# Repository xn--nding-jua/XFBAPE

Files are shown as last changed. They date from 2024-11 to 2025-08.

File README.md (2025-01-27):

# X-f/bape - A DIY expansion-card for the Behringer X32

This repository contains the firmware for the X-f/bape DIY-ExpansionCard for the Behringer X32. This project
is based on the f/bape Audioplayer-project.

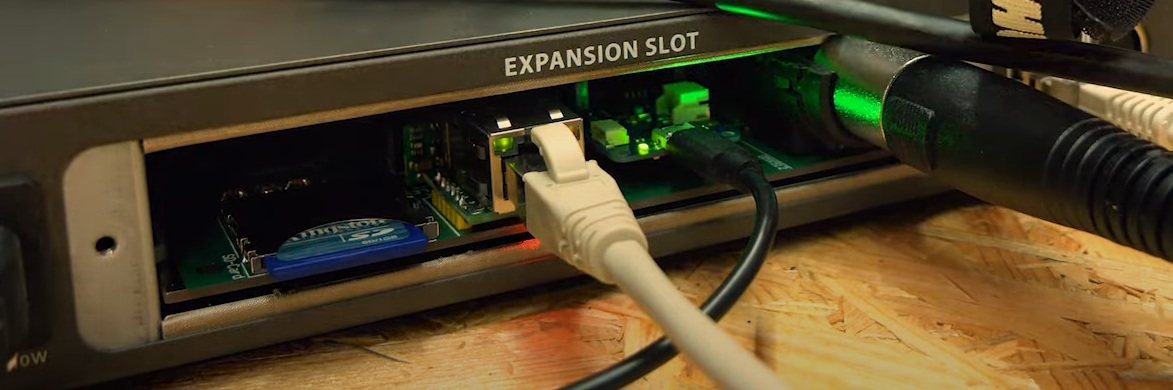
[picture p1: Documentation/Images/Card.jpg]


(https://www.youtube.com/watch?v=Q8K0aeqDBiI)

Three individual devices are part of this repository:

* Atmel/Microchip SAMD21 ATSAMD21G18A Cortex-M0+ 32-Bit Microcontroller
* Intel Cyclone 10LP 10CL016 FPGA
* uBlox NINA W102 (ESP32 D0WDQ6 Dual-Core)

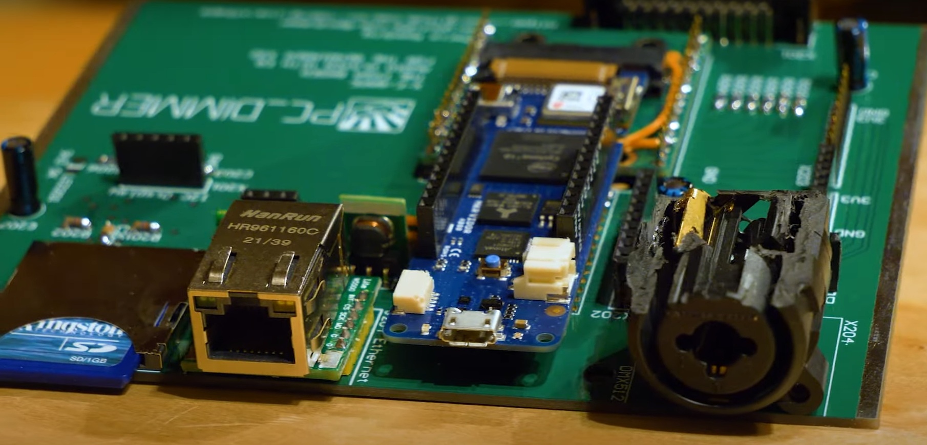
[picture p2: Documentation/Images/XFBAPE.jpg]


## Main-Features of the system
- [x] Card receives, mix and sends 32 audio-channels with 48kHz and 24bit
- [x] MP3-Playback via SD-Card
- [x] Card-playback can be controlled via original X32-Card-interface
- [x] Control via Webinterface (only WiFi and only Audio yet)
- [x] Control via multiple X-Touch-controls via ethernet (Audio and DMX512)
- [x] Control via original Behringer X32Edit (via ethernet)
- [x] Control via X32-surface using MackieMCU-emulation via Card-MIDI (Audio and DMX512)
- [x] Control via ASCII-based commands via USB, WiFi and Ethernet (Audio and DMX512)
- [x] DMX512-output (adjustable DMX-timings via VHDL)
- [x] Parametric-Equalizers (3 to 5, depending on the free space in FPGA)
- [x] Dynamic Audio-Compression (Stereo)

Optional / prepared features:
- [x] control card via MQTT when using NINA W102 in Client-Mode WiFi
- [x] multi-channel analog Audio-Output via PDM / sigma-delta-modulation
- [x] Noise-Gates
- [x] Bluetooth-A2DP-Sink (larger ESP32 is nescessary)
- [x] 24dB/oct Linkwitz-Riley Crossover for tweeter and subwoofer (larger FPGA is nescessary)

## Current status of the project
This project is ready for smaller events. Audio-processing, audio-effects and DMX512 is working as well as support for MackieMCU-control via X32 or the X-Touch-Control via Ethernet.

However, as this project is a Hobby-project, please be aware, that this software/hardware-combination is not yet tested well. Everything seems to work somehow, but bugs will be here and there.

Some known bugs and limitations:
- [ ] Medium: EQs crackle on adjusting the frequency -> problem is solved when using a steep low-pass-filter with a cutoff frequency <=24kHz. No solution for the small FPGA within the Vidor4000
- [ ] Low: MP3 files must have the same samplerate (44,1kHz or 48kHz) as the main-console - otherwise the playback has some minor "hiss/noise". There is not enough space in the used FPGA to implement a samplerate-conversion yet.
- [ ] Low: Bluetooth is not working together with other features -> optimize code in NINA/ESP32 to save more space to enable BT. Probably not possible with the NINA-W102 on the Vidor4000

Usage of the components:
- FPGA: Logic Elements 97% of 15,408 LE / 9-bit Multiplier: 61% of 112 Multipliers
- SAMD21: 30% of 256kB / 58% of dynamic memory
- NINA-W102: 83% of 2 MB flash-memory

## Overview
The SAMD21 is used as an USB-2-UART converter for controlling and updating the individual devices. The device also controls the small I2C-display and communicates over the W5500-IC with your ethernet.
The FPGA receives audio-data via four TDM connections and control data via an UART-connection from the NINA W102. It also implements parametric equalizers, 36-channel volume-controls and a dynamic compression. A 24dB/oct Linkwitz-Riley Crossover is prepared but does not fit into the small FPGA yet.
The uBlox NINA W102 (ESP32) acts as a WiFi Accesspoint with webserver and implements the SD-card interface with MP3-decoder. It can be used to adjust audio-volume, select MP3-tracks adjust the equalizer and other functions of the system. It feeds the audio-data via I2S to the FPGA. It can be used to act as a Bluetooth-A2DP-sink as well.

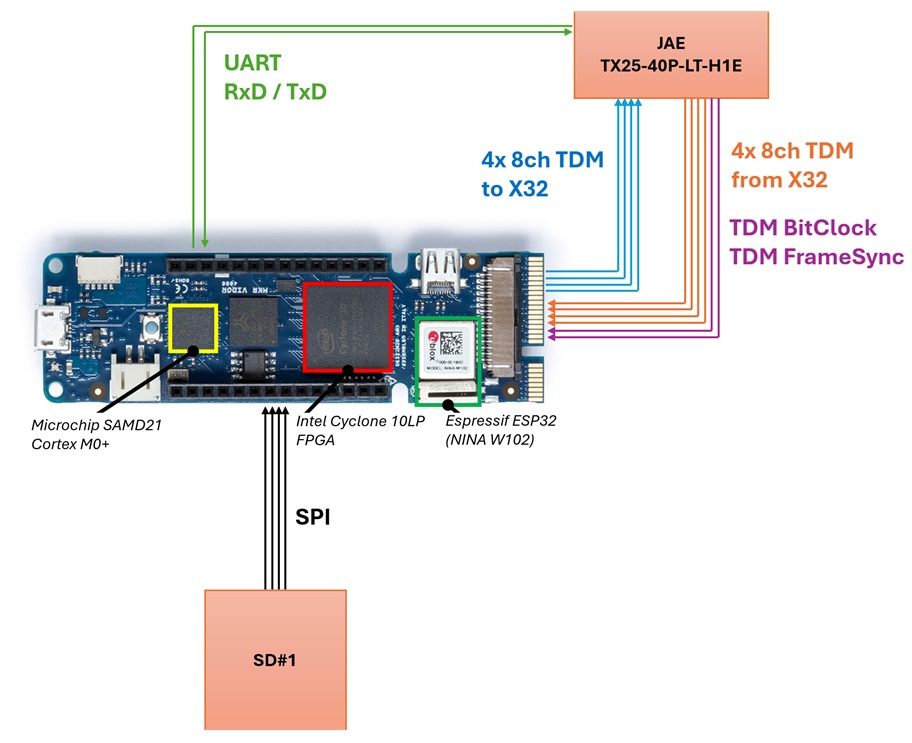
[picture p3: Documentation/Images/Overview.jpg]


As the original routing-functions of the Behringer X32 can still be used to route the individual channels, we are gaining more degree of freedom:
Using the 32 regular channels of the X32 and routing additional 32 channels from the AES50-connection to the X-f/bape-card, we can mix up to 64 channels in realtime with the X32. The X-f/bape will feed a submix to two of the 32 return-channels, that can be routed to two of the 6 AUX-Channels.
As the Cyclone 10LP is not the largest FPGA we are a bit limited with the EQing, but a 3-band PEQ with Compression is added to the submix.

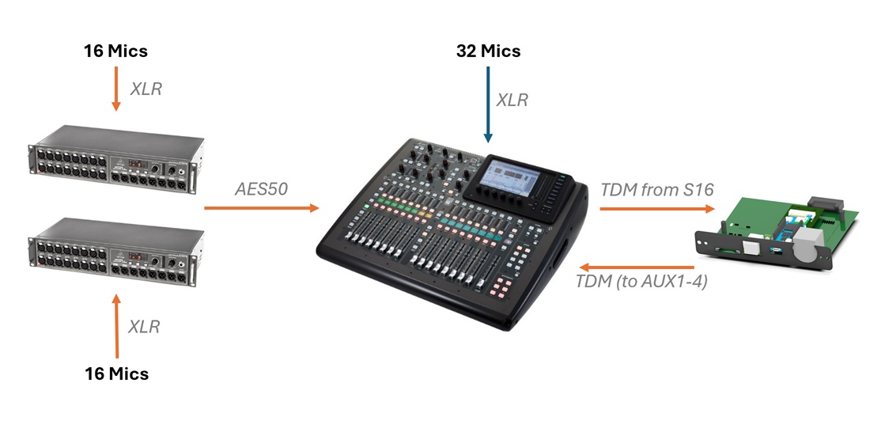
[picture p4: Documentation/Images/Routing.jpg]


## Connections
USB -> SAMD21 <-> FPGA <-> ESP32

## Uploading/Updating the firmware(s)
As this system uses several controllers and ICs, a total of three different firmwares have to be compiled and uploaded. The USB-port is connected to the SAMD21. So this is the first place for updates. As the SAMD21 acts as a JTAG-uploader for the FPGA, too, it will upload the bitstream for the FPGA together with its firmware. Finally, the SAMD21 can be set to an upload-mode, to update the NINA W102-module (ESP32).

### SAMD21 with bitstream for Intel Cyclone 10-FPGA
Start Intel Quartus Prime Lite and compile the logic. If you alreade have a file "bitstream.h" this is not nescessary. As the FPGA bitstream is part of the SAMD21 firmware, you have to update the FPGA-bitstream using this command before uploading the code to SAMD21:
    update_fpga_bitstream.bat

This batch-file will call the following command, to convert the TabularTextFile (TTF) into an Arduino-Header:

    ..\FPGA\Tools\vidorcvt\vidorcvt.exe < ..\FPGA\output_files\Audioplayer.ttf > bitstream.h
	
Now start the Arduino IDE in version 2.x. Connect the SAMD via USB and connect Arduino IDE to the designated port. Select "Arduino MKR Vidor 4000" as board and upload the software using the regular upload-functions of Arduino IDE. Next to the regular Arduino upload-function, the software bossac.exe can be used to upload the firmware without Arduino IDE:

* connect SAMD21 via USB
* initialize the bootloader of the SAMD21:
`mode COM5: BAUD=1200 parity=N data=8 stop=1 > nul`
upload the firmware
`bossac.exe --port=COM21 -I -U true -e -w Audioplayer.ino.bin -R`

Caution: As the power-demand of this board is quite high, use a sufficient power-supply for your USB-hub and a good cable!

### NINA WiFi-module
A firmware-update to the ESP32 is only possible, when SAMD21-controller is set to "passthrough-mode" so that an UART communication to the ESP32 is possible directly through SAMD21 and the FPGA. So first, open a terminal and send the following command to the SAMD21:

    samd:update:nina
Alternatively you can open the updatemode using windows-command-line (in this example the Vidor is connected to COM5):

    echo samd:update:nina > COM5
Then use the Arduino IDE to upload the new software using the built-in uploading-functions for the ESP32 uBlox NINA W102. An upload is possible using the esptool.exe, directly:

    Tools\esptool.exe --chip esp32 --port COM5 --baud 921600 --before default_reset --after hard_reset write_flash -z --flash_mode dio --flash_freq 80m --flash_size 2MB 0x1000 Update\NINA.bootloader.bin 0x8000 Update\NINA.partitions.bin 0xe000 Tools\boot_app0.bin 0x10000 Update\NINA.bin
After uploading the new firmware, please reset the board using the RESET-button.

### Some pitfalls
[x] Don't forget to close the COM-port-connection, when trying to upload the SAMD-firmware
[x] COM-ports above "9" (hence, two-digit-COM-ports) seem to rise some problems on later Windows 11 releases. The command "echo samd:update:nina > COM10" works under Windows 10, but not under Windows 11 24H2. Same when uploading to NINA W102/ESP32. So switch to a COM-port below 10 if you have problems.
[x] Sometimes the bootloader of the SAMD21 is not called correctly. If the Arduino IDE seems to wait for a longer time, double-press the RESET-button on the Vidor4000 to call the bootloader manually

## Graphical User Interfaces

There are several options to control this system:
* Directly on X32 using the MIDI-Remote in MackieMCU-mode (directly via Expansion Slot)
* X-Touch via Ethernet (multiple X-Touch are supported)
* WiFi via integrated Webinterface
* UART via FBAPE.EXE
* via ASCII-commands via UART and Ethernet

Here are some pictures to demonstrate the usage:

MP3s can be played using the original X-LIVE-Controls:
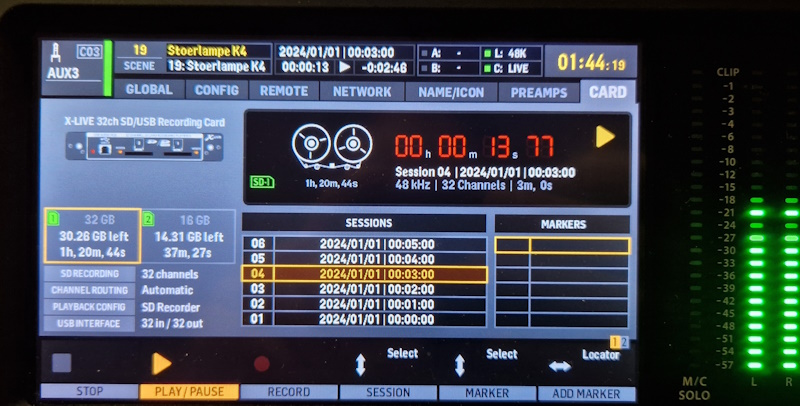
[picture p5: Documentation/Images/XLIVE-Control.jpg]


32-Audio channel and DMX512 can be controlled using the X32 in MIDI-Remote-Mode:
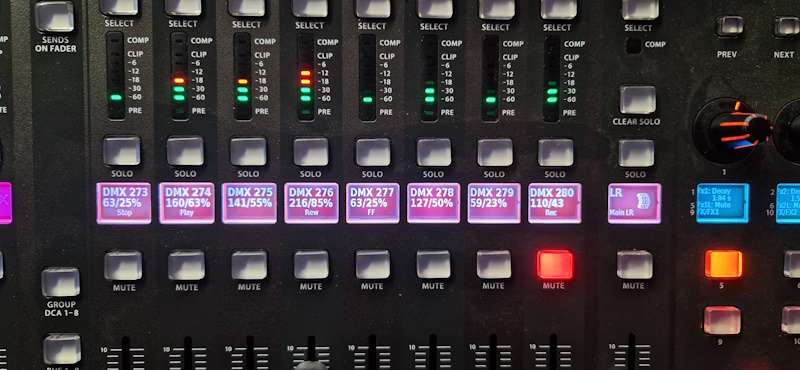
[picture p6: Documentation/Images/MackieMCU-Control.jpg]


The X-Touch are supported as well:
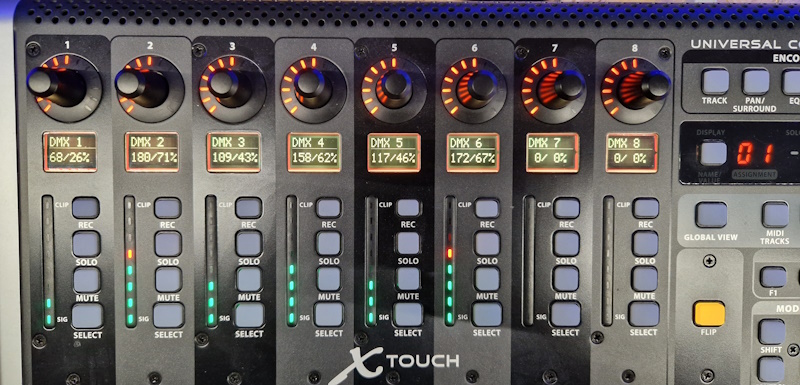
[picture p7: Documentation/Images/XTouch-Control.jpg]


The Windows-GUI is available as Windows11-App
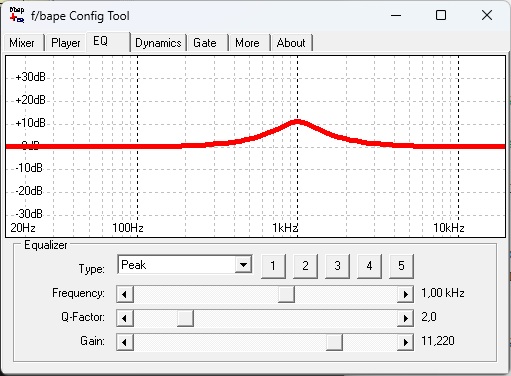
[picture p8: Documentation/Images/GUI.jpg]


As the Ethernet-Contoller is connected only to the SAMD21, the webinterface of the NINA-W102 cannot be accessed. Maybe we can change this in a later design. But for now the ethernet-port is limited to plain ASCII-commands.

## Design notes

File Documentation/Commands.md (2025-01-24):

# Overview of X-FBAPE Command-System
The X-FBAPE supports multiple ways to control the system:
1. USB-connection
2. TCP-Connection
3. WiFi
4. X32-Surface

In this document the ASCII-commands are described using the connection types 1 to 3. Here both microcontrollers, the SAMD21 and the NINA W102, can be accessed individually. The SAMD21 owns the USB- and TCP-Connection and passes all commands to the NINA, that not start with a "samd:".

## Commands related to SAMD
The SAMD controls the X-Touch, the MackieMCU emulation and the X32-Surface. So it controls the color of X-Touch displays, the channel-names and more:

* samd:ver?
> Returns a short version-information as String
* samd:*IDN?
> Returns a detailed information about the system as String
* samd:info?
> Returns a multi-line device information about the system as String
* samd:update:nina
> Sets the NINA W102 into an serial-update-mode and tunnels all UART-communication between USB and NINA-W102. So the regular "Upload firmware"-option in Arduino IDE can be used to upload a new NINA-firmware.
* samd:passthrough:nina@0 / samd:passthrough:nina@1
> Passthrough all serial-data from NINA not starting with "samd:" to the USB-port.
* samd:debug:nina@0 / samd:debug:nina@1
> Passthrough all serial-data from NINA to USB-port, even if it contains "samd:"
* samd:debug:x32@0 / samd:debug:x32@1
> Passthough all communication from X32 to the USB-port.
* samd:config:mac?
> Returns the current MAC-address read from the EEPROM as String.
* samd:config:ip?
> Returns the current IP-address of the SAMD21
* samd:config:set:ip@192.168.0.42
> Sets the IP-address of SAMD21 to the given address
* samd:config:set:xtouchipX@192.168.0.43
> Sets the IP-address of X-Touch X to the given address. X ranges from 1 to XTOUCH_COUNT with SAMD.h
* samd:setname:chX@Y
> Sets the channel-name of channel X to String Y. X ranges from 1 to 32
* samd:setcolor:chX@Y
> Sets the channel-colorof channel X to Y. X ranges from 1 to 32
> Valid values for Y are 0=black, 1=red, 2=green, 3=yellow, 4=blue, 5=pink, 6=cyan and 7=white
> Adding 64 to these values inverts the second line of display.
* samd:setname:dmxchX@Y
> Sets the channel-name of channel X to String Y. X ranges from 1 to 512
* samd:setcolor:dmxchX@Y
> Sets the channel-colorof channel X to Y. X ranges from 1 to 512
> Valid values for Y are 0=black, 1=red, 2=green, 3=yellow, 4=blue, 5=pink, 6=cyan and 7=white.
> Adding 64 to these values inverts the second line of display.
* samd:config:save
> Saves IP-addresses of device and X-Touch to EEPROM

## Commands related to NINA W102
The NINA-W102 (ESP32) is the main-control of the system and has more options compared to the SAMD21:

### Commands related to WiFi
* wifi:ssid@X
> sets the WiFi SSID to the String X
* wifi:password@X
> sets the WiFi password to the String X
* wifi:ip?
> Returns the current IP-address as String
* wifi:ip@192.168.0.42
> Sets the IP-address to the given address (but does not restart the WiFi!)
* wifi:gateway@192.168.0.1
> Sets the IP-gateway to the given address (but does not restart the WiFi!)
* wifi:subnet@255.255.255.0
> Sets the IP-subnet to the given subnet (but does not restart the WiFi!)
* wifi:mode@0 / wifi:mode@1
> Sets the WiFi to either 0=Client or 1=Access-Point (but does not restart the WiFi!)
* wifi:enabled@0 / wifi:enabled@1
> Turns the WiFi off (if 0) or (Re-)Initializes the WiFi (if 1)
* wifi:mqttserver@192.168.0.33
> Sets the mqtt-server to the given IP-address

### Commands related to playback-control
* player:filesize?
> Returns the current filesize in bytes as String
* player:file@filename.mp3
> Sets the given filename as new file
* player:stream@http://play.mp3.com
> Connects to the given host to play mp3 or m3u
* player:currentfile?
> Returns the current audio-file as String
* player:toc?
> Returns the content of the SD-file as CSV-String
* player:play
> Plays the current audiofile
* player:loop@0 / player:loop@1
> Enables or disables the loop of an audio-file
* player:pause
> Pauses or resumes the current audio-file
* player:stop
> Stops the current audio-file
* player:duration?
> Returns the duration of the current audiofile in seconds as String
* player:position?
> Returns the current position in seconds as String
* player:position@X
> Sets the current play-position to the given position X as String in seconds
* player:percent@X
> Sets the current play-position to the given position X as String in percent
* player:select@X
> Selects the track number X, but does not start the playback
* player:next
> Plays the next track on the SD-card
* player:prev
> Plays the previous track on the SD-card
* player:volume@X
> Sets the internal volume of the player in dBfs. X ranges from -140 to 0

### Commands related to bluetooth
Several commands are prepared but due to the lack of internal flash-space in the NINA-W102 these functions cannot be used at the moment. When using a larger/more modern ESP32, you can enable the bluetooth features. The FPGA is already prepared to play the I2S-stream of an A2DP-source.

### Commands related to audio-mixing
* mixer:volume:main@X
> Sets the volume of the main-channel to X in dBfs. X ranges from -48 to 6
* mixer:balance:main@X
> Sets the balance of the main-channel to X in percent. X ranges from 0 to 100 with 50 as center.
* mixer:volume:sub
> Sets the volume of the sub-channel to X in dBfs. X ranges from -48 to 6
* mixer:volume:chX@Y
> Sets the volume of channel X to Y in dBfs. X ranges from 1 to 32 and Y from -48 to 6
* mixer:mute :chX@Y
> Mutes channel X if Y is 1 or unmutes it if Y is 0. Multiple channels can be muted at the same time.
* mixer:solo:ch
> Enables solo for channel X if Y is 1 or disables solo it if Y is 0. Multiple channels can be solo-enabled at the same time.
* mixer:volume:card@X
> Sets the volume of the sd-card-channel to X in dBfs. X ranges from -48 to 6
* mixer:balance:chX@Y
> Sets the balance of channel X to Y in percent. X ranges from 1 o 32 and Y from 0 to 100 with 50 as center.
* mixer:reset
> Initializes all channels and effects (including EQs and compressors) to the default values

### Commands related to EQing and effects
* mixer:eq:reset
> Resets all EQs to the default values
* mixer:dynamics:reset
> Resets all compressors and gates to the default values
* mixer:eq:peqX@A,B,C,D
> Sets EQ X to type A, frequency B, quality C and gain D.
> X ranges from 1 to 5
> A ranges from 0=Allpass, 1=peak, 2=LowShelf, 3=HighShelf, 4=Bandpass, 5=Notch, 6=LowPass, 7=HighPass
> B ranges from 10 to 20000
> C ranges from 0.2 to 10
> D ranges from -20 to 20
* mixer:eq:bypassX@Y
> Bypasses EQ X if Y is 1
* mixer:eq:lp@X
> Sets frequency of low-pass to X Hz
* mixer:eq:hp
> Sets frequency of high-pass to X Hz
* mixer:adc:gainX@Y
> Sets gain for adc X to Y dB.
* mixer:gateX@A,B,C,D,E
> Sets Noisegate X to Threshold A, Range B, Attack C, Hold D and Release E
> A and B ranges from -60 to 0
> C, D and E ranges from 0 to 2000 ms
* mixer:compX@A,B,C,DE,F
> Sets dynamic compressor X to Threshold A, Ratio B, Makeup C, Attack D, Hold E, Release F
> A ranges from -60 to 0
> B ranges from 0=Limiter, over 1=1:1 to 8=1:64
> C ranges from 0 to 48
> D, E and F ranges from 0 to 2000 ms

### Commands related to DMX512
* dmx512:output:chX@Y
> Sets DMX512 channel X to value Y.
> X ranges from 0 (Startbyte, leave it value 0!), 1=channel 1 to 512
> Y ranges from 0 to 255

### Additional Commands

* ver?
> Returns a short version-information of the main-control as String
* *IDN?
> Returns a detailed information about the main-control as String
* info?
> Returns a multi-line device information about the main-control system as String
* fpga:ver?
> Returns a short version-information of the FPGA-bitstream as String
* fpga:*IDN?
> Returns a detailed information about the FPGA-bitstream system as String
* system:debug:fpga@0 | system:debug:fpga@1
> Enables or disables direct passthrough of the FPGA-communication to the SAMD21 and then the USB-connection
* system:init
> Initializes the main-controller. This function is called automatically at boot
* system:stop
> Stops the main-controller and disables all timers
* system:card:init
> Reinitializes the SD-Card. Useful if you remove and reinserts the card
* system:config:read@file.cfg
> Read the given file from SD and executes commands line-by-line. You can use all commands you find in this file
* system:config:write@file.cfg
> Writes the current configuration of the main-controller to the given file
* system:wificonfig:write
> Writes the current WiFi-configuration to the file "wifi.cfg". Caution: the file uses plain-text-passwords!!!

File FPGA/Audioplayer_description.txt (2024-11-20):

f/bape FPGACtrl for Arduino MKR Vidor4000 Device
v1.6.0 built on 10.06.2024
Infos: https://www.github.com/xn--nding-jua/Audioplayer

Copyright (c) 2023-2024 Dr.-Ing. Christian Noeding

This program is free software: you can redistribute it and/or modify
it under the terms of the GNU General Public License as published by
the Free Software Foundation, either version 3 of the License, or
(at your option) any later version.

This program is distributed in the hope that it will be useful,
but WITHOUT ANY WARRANTY; without even the implied warranty of
MERCHANTABILITY or FITNESS FOR A PARTICULAR PURPOSE.  See the
GNU General Public License for more details.

You should have received a copy of the GNU General Public License
along with this program.  If not, see <https://www.gnu.org/licenses/>.

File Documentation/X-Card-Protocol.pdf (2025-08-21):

### Unofficial Documentation of the Behringer X32 Expansion-Slot Protocol

v1.1, 21.08.2025

More Information about a DIY card using these commands: https://www.github.com/xn--nding-jua/xfbape

## Inhalt

# 1.X-LIVE

## 1.1. Playback Commands

These commands are the most useful for a DIY card. They can be used to control MP3-player or other functions using the GUI of the X32-hardware (console) or the X32-Edit.

### 1.1.1.Select session

Command: | *9B SESSIONNAME #Q#
Example: | *9B582100A0#Q#
Answer: | *9B000 MARKERCOUNT CHANNELCOUNT 0 NUMBEROFTOTALSAMPLES 0 ???
Example: | *9B0000232000F4E900000000000#

### 1.1.2.Play session

Command: | *9D#
Answer: | *9D00#

### 1.1.3.Pause session

Command: | *9E#
Answer: | *9E00#

### 1.1.4.Stop session

Command: | *9F#
Answer: | *9F00#

If recording has stopped, card answers with a bunch of additional information using *9Ncommands to update the GUI.

### 1.1.5.Seek session

Command: | *9M SAMPLEINDEX #Q#
Example: | *9M0009EDC0#Q#
Answer: | *9M00#

### 1.1.6.Request first entry of TOC

Command: | *9AF#
Answer: | *9ASF TITLE #
Example: | *9ASF582100A0#

### 1.1.7.Request additional TOC-entries

Command: | *9AN#
Answer: | *9ASF TITLE #
Example: | *9ASF582100A0#

If there are no more entries, card sends a *9AEN#

### 1.1.8.Sending current sampleindex while playing

Answer: | *9N22 SAMPLEINDEX#
Example: | *9N22000004BF#

Sends the current playback-position as sampleindex to the X32

### 1.1.9.Sending “alive” command

Answer: *8BE#

This message has to be sent every 5 seconds

## 1.2. Vital Commands

Vital Commands have to be implemented to identify the installed cards and cause the X32 console to load the desired user-interface (especially the X-LIVE-controls). Most of the commands are called only once.

### 1.2.1.Identification of card

Command: | *8I# and | *8R#
Answer: | *8 NAME : FIRMWAREVERSION #
Example: | *8X-UREC:A:12#

Up to now, the following card-strings are tested:
- *8X-UREC:A:12#
- *8DN32-UREC:A:12#
- *8X-DANTE:A:1#
- *8X-MADI:A:2#
Based on screenshots of setup-screens, the following strings should work, too:
- *8X-USB:A:2#
- *8X-UF:A:1#
- *8X-ADAT:A:2#

### 1.2.2.Request size of card

Command: | *9N#
Answer: | *9N CARDNUMBER 0 CARDSIZE USEDSPACE #
Example: | *9N1001DB830000200000#

Caution: the calculation is not correct at the moment. Card-Size is shown correctly, but used space to calculate remaining time is not correct.

### 1.2.3.Request total size(?)

Command: | *9G#
Answer: | *9G CARDNUMBER 0 CARDSIZE1+CARDSIZE2 #
Example: | *9G1003B70600#

Its not clear, why we have to transmit the total size here.

### 1.2.4.Request markers

Command: | *9C MARKERINDEX#
Example: | *9C02#
Answer: | *9C00 MARKERINDEX TIMEINDEX#
Example: | *9C0002000004BF#

Important: with markerindex = 0 the total length of the current session is transmitted:
Example: | *9C00#
Answer: | *9C0000 TOTALSAMPLES#

## 1.3. Additional Commands

Additional Commands are “nice to have” and allow additional communication between X32 and a DIY card. But some of the have no special usage for a DIY card at the moment.

### 1.3.1.Switch between USB and SD-Card

Command: | *8C8 OPTION DEVICE#
Example: | *8C81C#
Answer: | *8Y#

Option contains number between 0 and 5, to select number of channels to record Device can be “C” for Card and “U” for USB

### 1.3.2.Detecting a new SD-card

Answer: | *9N CARDINDEX 0 00007F40 00000000#
Example: | *9N1000007F4000000000#

At the moment it is unclear, why 7F40 is sent. It represents 32576 in decimal and has no direct meaning on the first view.

### 1.3.3.Delete Session

Command: | *9X SESSIONNAME #
Example: | *9X582100A0#
Answer: | *9Y00#

### 1.3.4.Start recoding new session

Command: | *9H SESSIONNAME #
Example: | *9H582100A0#
Answer: | *9Y00#

### 1.3.5.Format SD-Card

Command: | *9Q~#
Answer: | *9Y00#*9N0700000000##

### 1.3.6.Create new marker

Command: | *9I SAMPLEINDEX #
Example: | *9I000004BF#
Answer: | *9Y00#

### 1.3.7.Select SD-Card

Command: | *9R CARD #
Example: | *9R0# or | *9R1#
Answer: | *9R00#

### 1.3.8.Initialization-Commands

Command: | *_G 5-DIGIT NUMBERS#
Example: | *3G70000#
Answer: | no

# 2.Other X-Cards

Beside the X-LIVE (or DN32-LIVE) there are several other cards that can be used. Most of the cards have limited functions compared to the X-LIVE card: X-UF, X-USB and X-ADAT have no special functions beside the conversion of 4x 8 channel TDM-streams to USB or ADAT.
Only X-MADI and X-DANTE cards have some special features, that could be interesting: X-MADIcards can be used as clock-master, hence the samplerate of the console can be clocked by a DIY-card.

## 2.1. X-ADAT

### 2.1.1.Enable/Disable external Word-Clock

Command: | *8C4Y#
Anwer: | *8Y#
Command: | *8C4N#
Anwer: | *8Y#

State of Word-Clock can be checked using *8S# command

### 2.1.2.Read State-Command

Command: | *8S#
Answer: | *8YN#

First “Y” is for acknowledgement of the state-command, second characters gives information about the state of the external Word-Clock: Y → external Word-Clock is used, N → Word-Clock is disabled.

## 2.2. X-MADI

Kudos to Lorenzo, the following commands are known for X-MADI:

### 2.2.1.Read State-Command

Command: | *8S#
Answer: | *8YY#

### 2.2.2.MADI-channel routing

Command: | *8C CHANNELMODE INPUTCHANNELS OUTPUTCHANNELS#
Example: | *8C631B# | for 64-channel-mode with 17-48 for input and 1-32 for output
Answer: | *8Y#
“Channel” = 5 for 56 channel MADI-mode, “Channel” = 6 for 64-channel MADI-mode

The possible command-combinations can be:
Input | Output | Channels
0 | 0 | None (?)
1 | 1 | 1-32
2 | 2 | 9-40
3 | 3 | 17-48
4 | 4 | 25-56
5 | 5 | 33-64

### 2.2.3.Set fiber-optic / coaxial

Command: | *8C601 OPTION#
Example: | *8C601O# for fibre-optical
Answer: | *8Y#
With “Option” = “C” for coaxial (redundancy) and “Option” = “O” for fibre-optical (priority)

# 3.General information

### 3.1.1.Enconding of values as HEX-string

All information regarding card-sizes, position-information, etc. are transmitted as 8-digit HEXvalues. So all values have to be converted to HEX-strings.

### 3.1.2.Used timecode for session-names

The X32 uses a specific timecode based on the year 1980. Day, month, year and timeinformation are compressed into a 32-bit-value, represented by a 8-digit HEX-string:

For enconding the timecode, the following code can be used:

String encode(uint8_t day, uint8_t month, uint16_t year, uint8_t hour, uint8_t minute, uint8_t second) {
uint32_t timecode = (uint32_t)((year - 1980)) << 25;
timecode += (uint32_t)month << 21;
timecode += (uint32_t)day << 16;
timecode += (uint32_t)hour << 11;
timecode += (uint32_t)minute << 5; timecode += (uint32_t)second << 1;

return intToHex(timecode, 8);
}

Decoding a given timecode to a nice string can be done as follows:

String decode(String timecodeHex) {
uint32_t timecode = hexToInt(timecodeHex);

uint16_t year = (timecode >> 25) + 1980; uint8_t month = (timecode & 0x1FFFFFF) >> 21; uint8_t day = (timecode & 0x1FFFFF) >> 16; uint8_t hour = (timecode & 0xFFFF) >> 11;
uint8_t minute = | (timecode & 0x7FF) >> 5;
uint8_t second = | (timecode & 0x1F) << 1;

return String(day) + "." + String(month) + "." + String(year) + " " + String(hour) + ":" + String(minute) + ":" + String(second);
}

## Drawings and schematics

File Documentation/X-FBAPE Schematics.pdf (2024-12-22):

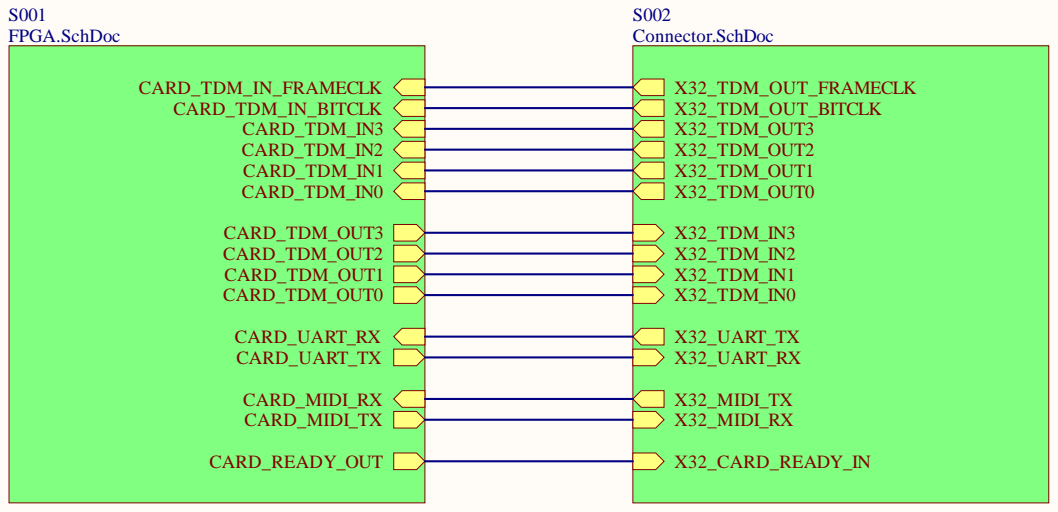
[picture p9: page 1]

Title
X-F/BAPE Expansion Card for Behringers X32
The Fpga Based AudioPlayer with Equalizers

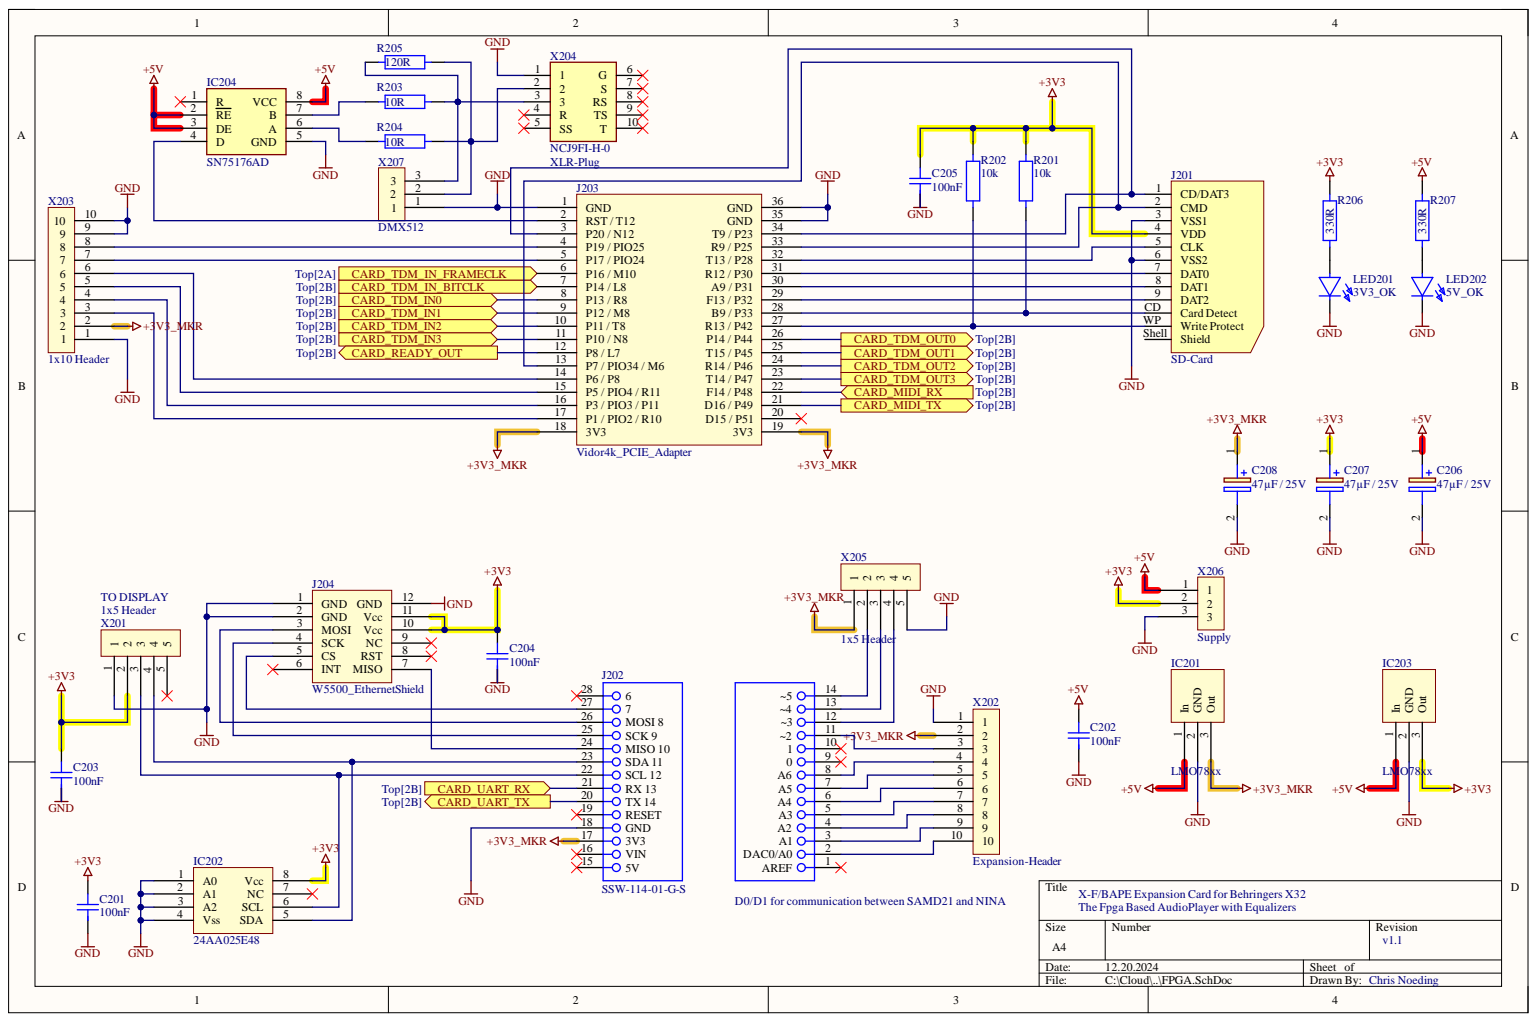
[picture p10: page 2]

P17 / PIO24 5
P16 / M10 6

Top[2B] CARD_TDM_IN_BITCLK | | P14 / L8 7
Top[2B] CARD_TDM_IN0 | | P13 / R8 8

P12 / M8 9 | Card Detect CD
P11 / T8 10
P10 / N8 11
P8 / L7 12
P7 / PIO34 / M6 13

P5 / PIO4 / R11 15

GND | P3 / PIO3 / P11 16

D0/D1 for communication between SAMD21 and NINA

Title
X-F/BAPE Expansion Card for Behringers X32
The Fpga Based AudioPlayer with Equalizers

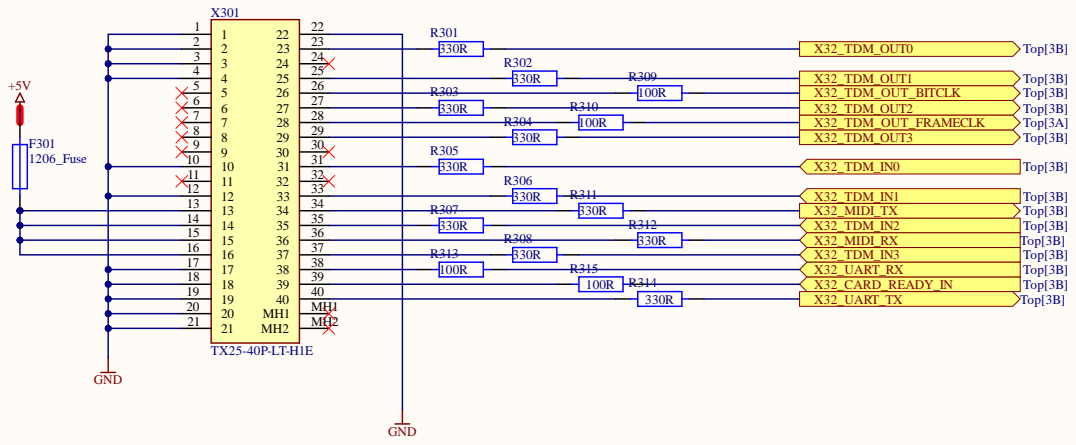
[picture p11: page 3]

1 4
1 5
1 6

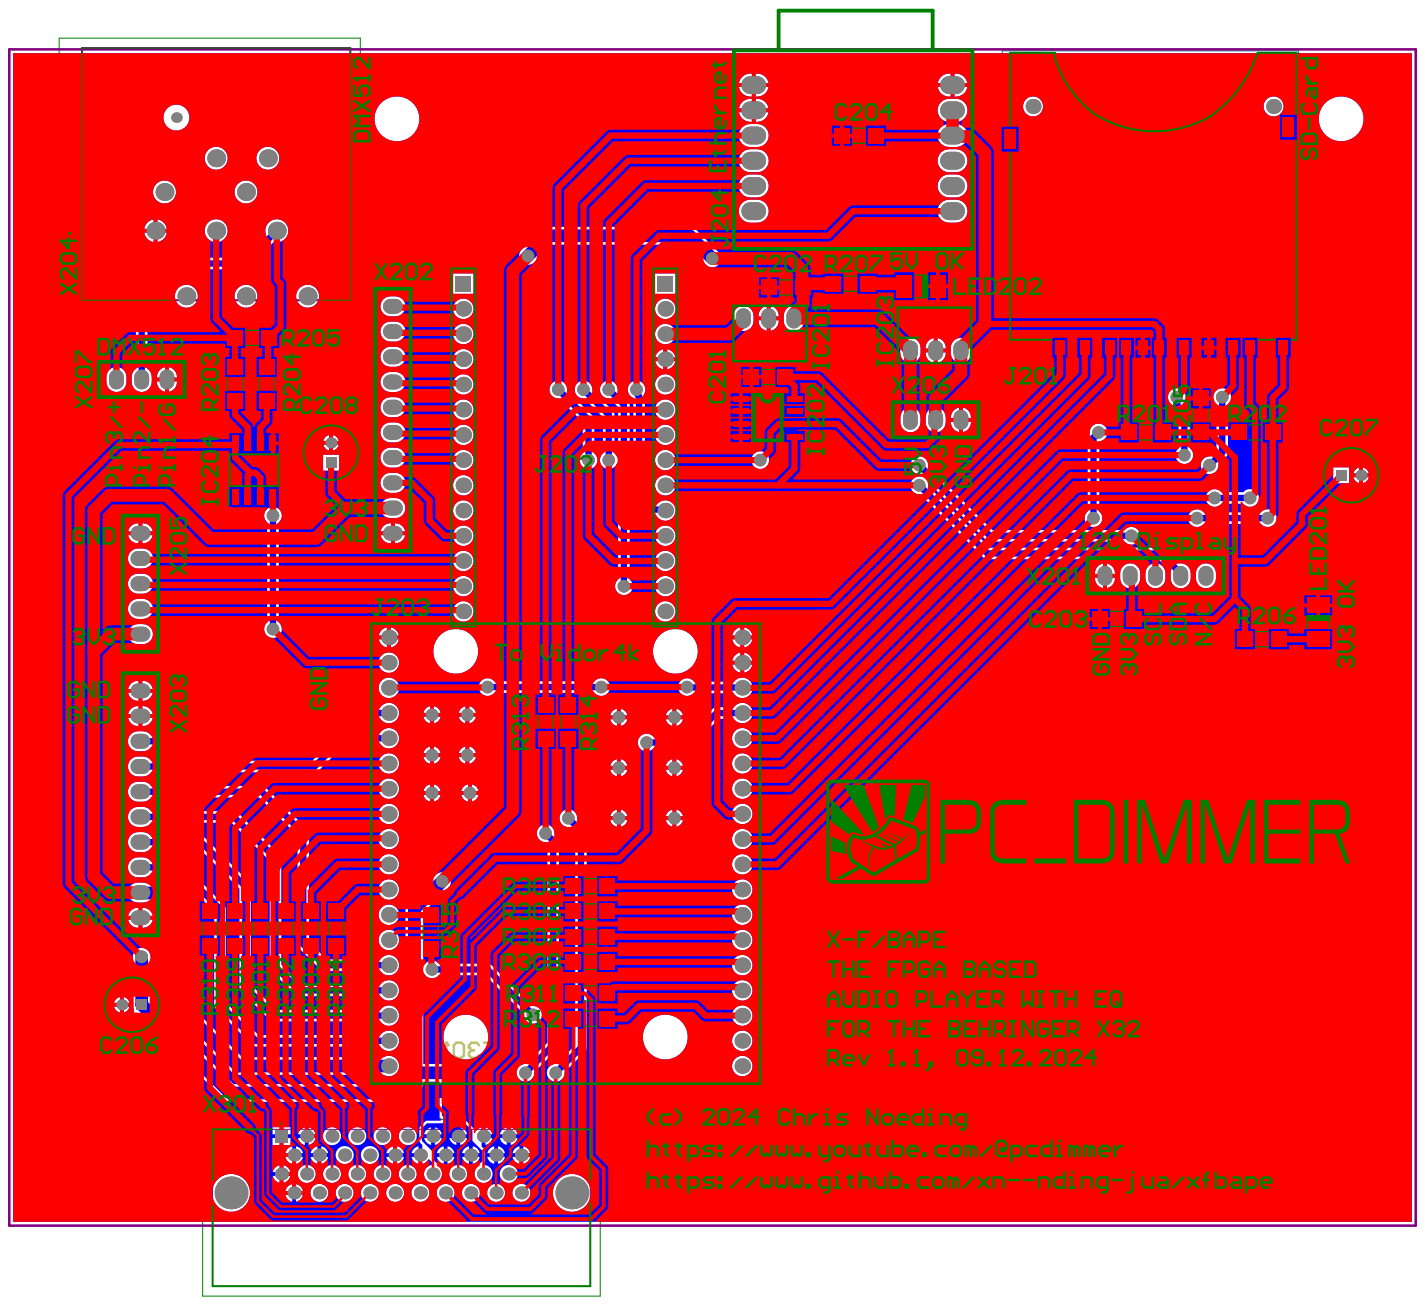
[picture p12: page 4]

Comment | Description | Designator | Footprint | LibRef | Quantity
100nF | 1206_C | C201, C202, C203, C204, C205 | 1206 | 1206_C_1nF/63V | 5
47µF/ 25V | Capacitor Polarised | C206, C207, C208 | CAPPRD200W50D550H 1250 | MAL214256479E3 | 3
1206_Fuse | 1206_Fuse | F301 | 1206 | 1206_Fuse | 1
LMO78xx | | IC201, IC203 | LMO78xx | LMO78xx | 2
24AA025E48 | | IC202 | SOIC-8 | 24AA025E48 | 1
SN75176AD | Integrated Circuit | IC204 | SOIC127P600X175-8N | SN75176AD | 1
693061010911 | WR-CRDSDCard Connector Push & Push with Card Detection | J201 | 693061010911 | 693061010911 | 1
SSW-114-01-G-S | SQPost Socket, Through-hole, Vertical, -55to 125 degC, 2.54mm Pitch, 14-Pin, Female, RoHS | J202 | SMTC-SSW-114-01-X-S | Arduino MKRVidor 4000 | 1
Vidor4k_PCIE_Adapter | | J203 | Vidor4K_PCIE_Adapter | Vidor4k_PCIE_Adapter | 1
W5500_EthernetShield | | J204 | W5500_EthernetShield | W5500_EthernetShield | 1
3V3_OK | LED3MM | LED201 | LED3MM | LED3MM | 1
5V_OK | LED3MM | LED202 | LED3MM | LED3MM | 1
10k | 1206_R | R201, R202 | 1206 | 1206_R | 2
10R | 1206_R | R203, R204 | 1206 | 1206_R | 2
120R | 1206_R | R205 | 1206 | 1206_R | 1
330R | 1206_R, 330R | R206, R207, R301, R302, R303, R304, R305, R306, R307, R308, R311, R312, R314 | 1206 | 1206_R | 13
100R | 1206_R | R309, R310, R313, R315 | 1206 | 1206_R | 4
1x5Header | | X201, X205 | 1x5Header | 1x5Header | 2
Expansion-Header | | X202 | 1x10Header | 1x10Header | 1
1x10Header | | X203 | 1x10Header | 1x10Header | 1
NCJ9FI-H-0 | Connector | X204 | NCJ9FIH0 | NCJ9FI-H-0 | 1
Supply | | X206 | 1x3Jumper | 1x3Jumper | 1
DMX512 | | X207 | 1x3Jumper | 1x3Jumper | 1
TX25-40P-LT-H1E | Connector | X301 | TX2540PLTH1E | TX25-40P-LT-H1E | 1

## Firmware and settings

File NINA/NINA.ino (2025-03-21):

/*
  X-f/bape MainCtrl for Arduino MKR Vidor4000 Device
  v3.1.5 built on 21.03.2025
  Infos: https://www.github.com/xn--nding-jua/xfbape
  Copyright (c) 2023-2025 Dr.-Ing. Christian Nöding

  Target-Board: uBlox NINA W10-series (ESP32)
  Board-package: https://espressif.github.io/arduino-esp32/package_esp32_index.json
  Flash-Frequency: 80 MHz
  Flash-Size: 2MB (16Mb, NINA W101/102)
  Arduino runs on: Core 1
  Partition Scheme: "Minimal SPIFFS (1.9MB APP with OTA/190KB SPIFFS)"
  Important: a specific, self-defined partition-scheme from partitions.csv within the NINA-folder will be used. If you want to use a different ESP32-chip, you have to delete or edit this file
  Upload Speed: up to 921600 is tested
  Current Flash-Usage: 1,441,909 bytes (73%) of program storage space. Maximum is 1,966,080 bytes.

  Description:
  =====================================================================
  This project runs on an ESP32 (NINA-W102-Module) and implements an audio-player with
  full-qualified interactive webserver using AJAX-technology for smooth update of the
  webinterface.
  The software implements Bluetooth-A2DP, SD-Card-Playback, MQTT, TCP-commandu-server,
  equalizer- and crossover-calculation and communication between FPGA and a USB-controller.

  Used libraries:
  =====================================================================
  - ESP32 Board-Libraries v3.1.1 (https://dl.espressif.com/dl/package_esp32_index.json)
  - SD-Card-Playback: ESP32-audioI2S v3.0.13 (https://github.com/schreibfaul1/ESP32-audioI2S)
  - Ticker v4.4.0 by Stefan Staub
  - PubSubClient v2.8 by Nick O'Leary
  - SimpleFTPServer v2.1.10 by Renzo Mischianti [change SD-settings in FtpServerKey.h if you have trouble connecting to SD-card]
      Alternative: ESP-FTP-Server-Lib by Peterus (https://github.com/peterus/ESP-FTP-Server-Lib) [supports only ACTIVE ftp-mode]
  - Bluetooth-Sink: ESP32-A2DP v1.8.1 by P. Schatzmann (https://github.com/pschatzmann/ESP32-A2DP)
  - AudioTools for Bluetooth-Playback: ArduinoAudioTools v0.9.8 by P. Schatzmann (https://github.com/pschatzmann/arduino-audio-tools)

  Information:
  ======================================================================
  As the space in the NINA-W102 module is limited, you can use older versions of
  ESP32 Board-Libraries (older than 3.0) and use the ESP32-audioI2S in version 2.0
  This will save several percent of flash space.

  License information:
  =====================================================================
  This program is free software: you can redistribute it and/or modify
  it under the terms of the GNU General Public License as published by
  the Free Software Foundation, either version 3 of the License, or
  (at your option) any later version.
  
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
  Pin information:
  =====================================================================
  +-------------+----------------+----------+------------+---------------+------------------------+----------------------------------------+
  | Arduino Pin | Arduino Analog | NINA Pin |  ESP32 Pin | FPGA Pin      |  Property              | Notes                                  |
  +-------------+----------------+----------+------------+---------------+------------------------+----------------------------------------+
  |             |                |          |    GPIO    |               |                        |                                        |
  |             |                | RESET_N  | RESET      | R1            | Reset-Pin              | RESET for NINA/ESP32                   |
  | D12         |                | PIO1     | 23         | T11           | SPI-MOSI               | SPI-MOSI (SD-Card)                     |
  | D19         | A6             | PIO2     | 34         | R10           |                        | -> UART2 TxD (MIDI)       (X204 Pin 3) |
  | D21         | A3             | PIO3     | 39         | P11           |                        | <- UART2 RxD (MIDI)       (X204 Pin 4) |
  | D20         | A0             | PIO4     | 36         | R11           |                        | free                      (X204 Pin 5) |
  | D16         | A4             | PIO5     | 32         | N6            |                        | SD I2S SerialClock                     |
  | D17         | A5             | PIO7     | 33         | P6            |                        | SD I2S WordClock                       |
  | D18         |                | PIO8     | 21         | N5            |                        | SD I2S SerialData                      |
  | D3          | A18            | PIO16    | 25         |               | DAC2 / LED Blue        |                                        |
  | D2          | A19            | PIO17    | 26         |               | DAC1 / LED Green       |                                        |
  | D5          | A17            | PIO18    | 27         | T5            |                        | -> UART1 TxD to FPGA                   |
  | D6          |                | PIO20    | 22         | R5            |                        | <- UART1 RxD to FPGA                   |
  | D11         |                | PIO21    | 19         | R6            | SPI-MISO               | SPI-MISO (SD-Card)                     |
  | D1          |                | PIO22    | 01         | E15           | SCI-TxD                | -> UART0 TxD to SAMD21                 |
  | D0          |                | PIO23    | 03         | T6            | SCI-RxD                | <- UART0 RxD from SAMD21               |
  |             | A10            | PIO24    | 04         |               |                        |                           (X204 Pin 8) |
  |             | A12            | PIO25    | 02         |               |                        |                           (X204 Pin 9) |
  | D7          | A11            | PIO27    | 00         | N9            |                        | BOOT-Pin to select Bootloader-Mode     |
  | D10         |                | PIO28    | 05         | N11           | SPI-SS                 | SPI-CS (SD-Card)                       |
  | D13         |                | PIO29    | 18         | T10           | SPI-SCK                | SPI-SCK (SD-Card)                      | 
  | D9          | A16            | PIO31    | 14         | T4            |                        |                                        |
  | D8          | A13            | PIO32    | 15         | J13           |                        | BT I2S SerialClock                     | ! pin controls Uart0 TxD Debug during boot
  | D4          | A7             | PIO34    | 35         | M6            |                        | BT I2S MClk                            |
  | D14         | A14            | PIO35    | 13         | R4            | I2C-SCL                | BT I2S WordClock                       |
  | D15         | A15            | PIO36    | 12         | N1            | I2C-SDA                | BT I2S SerialData                      | ! pin controls flash-voltage during boot
  +-------------+----------------+----------+------------+---------------+------------------------+----------------------------------------+

  Used files for Webserver:
  =====================================================================
  - Bootstrap-Theme v5.1.3: https://getbootstrap.com
  - Free Bootstrap-Theme: Bootswatch Cyborg: https://bootswatch.com/cyborg/
  - VUmeter: https://github.com/tomnomnom/vumeter
  - Smoothie-Charts: http://smoothiecharts.org
  - RoundSlider: https://roundsliderui.com
  - Plotly: https://plotly.com
  - jQuery: https://jquery.com
  - FontAwesome: https://fontawesome.com
  - Bootstrap for ESP https://techtutorialsx.com/2019/03/04/esp32-arduino-serving-bootstrap/
  - fetch API https://werner.rothschopf.net/201809_arduino_esp8266_server_client_2.htm
*/

#include "NINA.h"

void timerSecondsFcn() {
  //ledcFade(LED_GREEN, 255, 0, 500); // pin, StartDutyCycle, TargetDutyCycle, FadeTime in ms
  digitalWrite(LED_GREEN, !digitalRead(LED_GREEN));

  #if USE_MQTT == 1
    mqttPublish();
  #endif
  
  updateSamdInfo(); // update the display of the SAMD with current information
}

void timer100msFcn() {
  updateSamdChannel(); // update the display of the SAMD with current information
}

void setup() {
  pinMode(LED_GREEN, OUTPUT);
  pinMode(LED_BLUE, OUTPUT);
  //ledcAttach(LED_GREEN, 2000, 8); // IO-pin, frequency in Hz, Resolution in Bit
  ledcAttach(LED_BLUE, 2000, 8); // IO-pin, frequency in Hz, Resolution in Bit

  // init communication with SAMD21/USB
  // SAMD21 supports maximum 3Mbps: f_baud <= 48MHz/16. But everything above 921600 baud seems to be instable
  SerialSamd.begin(921600, SERIAL_8N1, 3, 1, false, 1000); // BaudRate, Config, RxPin, TxPin, Invert, TimeoutMs, rxfifo_full_thrhd
  //SerialSamd.begin(1228800, SERIAL_8N1, 3, 1, false, 1000); // 1.2288 Mbps results in communication-problems with computer

  // init communication with FPGA
  SerialFpga.begin(4000000, SERIAL_8N1, 22, 27, false, 1000); // BaudRate, Config, RxPin, TxPin, Invert, TimeoutMs, rxfifo_full_thrhd

  setX32state(false); // disable X32
}

void loop() {
  if (systemOnline) {
    // handle incoming messages from FPGA
    handleFPGACommunication(); // communication through software-serial

    // handle webserver
    webserver.handleClient();

    #if USE_TCPSERVER == 1
      handleTCPCommunication();
    #endif

    #if USE_MQTT == 1
      handleMQTT();
    #endif

    #if USE_FTP_SERVER == 1
      ftp.handleFTP();
    #elif USE_FTP_SERVER == 2
      ftp.handle();
    #endif
  }

  // handle incoming messages via serial-port
  handleUartCommunication(); // communication through hardware-serial
}

void initSystem() {
  // request identification from SAMD21
  SerialSamd.println("samd:*IDN?");

  #if USE_DISPLAY == 1
    // send version information to SAMD21
    SerialSamd.println("samd:version:main@" + String(versionstring)); // send MainCtrl version to SAMD21
  #endif
  
  // activate passthrough via SAMD21 to USB
  SerialSamd.println("samd:passthrough:nina@1");
  delay(100);
  // send welcome-text to USB
  SerialSamd.println("X-f/bape MainCtrl " + String(versionstring) + " built on " + String(compile_date));

  // init SD-Card
  initStorage();

  // initWifi
  //configRead("/wifi.cfg", 10); // read WiFi-settings with maximum of 10 lines (if file is available)
  initWifi(); // initialize WiFi

  /*
  // Bluetooth cannot coexist with our WiFi at the moment
  // so we will activate bluetooth manually with following commands
  // wifi:enabled@0
  // bt:enabled@1
  #if USE_BLUETOOTH == 1
    // init Bluetooth
    initBluetooth();
  #endif
  */

  #if USE_SDPLAYER == 1
    // init Audioplayer
    initAudio();
  #endif

  // init Webserver
  initWebserver(); // starting regular HTTP-server

  // init command-server
  #if USE_TCPSERVER == 1
    cmdserver.begin();
  #endif

  #if USE_MQTT == 1
    initMQTT();
  #endif

  #if USE_FTP_SERVER == 1
    ftp.begin(FTP_USER, FTP_PASSWORD);
  #elif USE_FTP_SERVER == 2
    ftp.addUser(FTP_USER, FTP_PASSWORD);
    ftp.addFilesystem("SD", &SD); // Alternative: ftp.addFilesystem("SPIFFS", &SPIFFS);
    ftp.begin();
  #endif

  // Initiate the timers
  TimerSeconds.attach_ms(1000, timerSecondsFcn);
  Timer100ms.attach_ms(100, timer100msFcn);

  #if USE_DMX512 == 1
    initDmx512();
    #if USE_DMX512_RX == 1
      initDmx512Receiver();
    #endif
  #endif

  // initialize the Audiomixer. Try to read configuration from SD
  //if (!configRead("/xfbape.cfg", 100)) { // read config-file with maxmimum of 100 lines - uncomment if you like to load configuration-file on startup
    // reading config-file failed -> load defaults
    initAudiomixer();
  //}

  // enable X32
  setX32state(true); // first command to SAMD21 should be *8I# followed by *8R# after around 250ms

  // set system-flag to online
  systemOnline = true;
}

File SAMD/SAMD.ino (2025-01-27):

/*
  X-f/bape USBCtrl for Arduino MKR Vidor4000 Device
  v3.1.4 built on 27.01.2025
  Infos: https://www.github.com/xn--nding-jua/xfbape
  Copyright (c) 2023-2025 Dr.-Ing. Christian Nöding

  Target-Board: Arduino MKR Vidor 4000 (Atmel SAMD21 32-bit CortexM0+ controller)
  Board-package: http://downloads.arduino.cc/Hourly/samd/package_samd-hourly-build_index.json

  Description:
  =====================================================================
  This Arduino-Project loads a bitstream to the Intel Cyclone10LP FPGA and
  communicates with USB-Host and NINA-W102-Module, which implements a full
  featured MP3, WAVE and AAC SD-Card-Player with WiFi-Webserver and A2DP-
  Bluetooth-Receiver.

  Used libraries:
  =====================================================================
  only when using OLED display:
  - Adafruit SSD1306 v2.5.10 by Adafruit (for I2C Display)

  License information:
  =====================================================================
  This program is free software: you can redistribute it and/or modify
  it under the terms of the GNU General Public License as published by
  the Free Software Foundation, either version 3 of the License, or
  (at your option) any later version.
  
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
  Pin information:
  =====================================================================
  +------------+------------------+--------+--------+-----------------+--------+-----------------------+---------+---------+--------+--------+----------+----------+-----------------------------------------------------------+
  | Pin number |  MKR  Board pin  |  PIN   |  FPGA  | Notes           | Peri.A |     Peripheral B      | Perip.C | Perip.D | Peri.E | Peri.F | Periph.G | Periph.H | Usage for Audioplayer                                     |
  |            |                  |        |        |                 |   EIC  | ADC |  AC | PTC | DAC | SERCOMx | SERCOMx |  TCCx  |  TCCx  |    COM   | AC/GLCK  |                                                           |
  |            |                  |        |        |                 |(EXTINT)|(AIN)|(AIN)|     |     | (x/PAD) | (x/PAD) | (x/WO) | (x/WO) |          |          |                                                           |
  +------------+------------------+--------+--------+-----------------+--------+-----+-----+-----+-----+---------+---------+--------+--------+----------+----------+-----------------------------------------------------------+
  | 00         | D0               |  PA22  |  G1    |                 |  *06   |     |     | X10 |     |   3/00  |   5/00  |* TC4/0 | TCC0/4 |          | GCLK_IO6 | -> Serial2 TxD -> FPGA G1 -> VHDL -> FPGA T6 -> NINA RxD  |
  | 01         | D1               |  PA23  |  N3    |                 |  *07   |     |     | X11 |     |   3/01  |   5/01  |* TC4/1 | TCC0/5 | USB/SOF  | GCLK_IO7 | <- Serial2 RxD <- FPGA N3 <- VHDL <- FPGA E15 <- NINA TxD |
  | 02         | D2               |  PA10  |  P3    |                 |   10   | *18 |     | X02 |     |   0/02  |   2/02  |*TCC1/0 | TCC0/2 | I2S/SCK0 | GCLK_IO4 | -> Expansion Header X202.3                                |
  | 03         | D3               |  PA11  |  R3    |                 |   11   | *19 |     | X03 |     |   0/03  |   2/03  |*TCC1/1 | TCC0/3 | I2S/FS0  | GCLK_IO5 | -> Expansion Header X205.4                                |
  | 04         | D4               |  PB10  |  T3    |                 |  *10   |     |     |     |     |         |   4/02  |* TC5/0 | TCC0/4 | I2S/MCK1 | GCLK_IO4 | -> Expansion Header X205.3 (MIDI Tx)                      |
  | 05         | D5               |  PB11  |  T2    |                 |  *11   |     |     |     |     |         |   4/03  |* TC5/1 | TCC0/5 | I2S/SCK1 | GCLK_IO5 | -> Expansion Header X205.2 (MIDI Rx)                      |
  | 06         | D6               |  PA20  |  G16   |                 |  *04   |     |     | X08 |     |   5/02  |   3/02  |        |*TCC0/6 | I2S/SCK0 | GCLK_IO4 | -> n/a                                                    |
  | 07         | D7               |  PA21  |  G15   |                 |  *05   |     |     | X09 |     |   5/03  |   3/03  |        |*TCC0/7 | I2S/FS0  | GCLK_IO5 | -> SPI-CS W5500 EthernetShield                            |
  +------------+------------------+--------+--------+-----------------+--------+-----+-----+-----+-----+---------+---------+--------+--------+----------+----------+-----------------------------------------------------------+
  |            |       SPI        |        |        |                 |        |     |     |     |     |         |         |        |        |          |          |                                                           |
  | 08         | MOSI             |  PA16  |  F16   |                 |  *00   |     |     | X04 |     |  *1/00  |   3/00  |*TCC2/0 | TCC0/6 |          | GCLK_IO2 | -> SPI-MOSI W5500 EthernetShield                          |
  | 09         | SCK              |  PA17  |  F15   |                 |  *01   |     |     | X05 |     |  *1/01  |   3/01  | TCC2/1 | TCC0/7 |          | GCLK_IO3 | -> SPI-SCK W5500 EthernetShield                           |
  | 10         | MISO             |  PA19  |  C16   |                 |   03   |     |     | X07 |     |  *1/03  |   3/03  |* TC3/1 | TCC0/3 | I2S/SD0  | AC/CMP1  | -> SPI-MISO W5500 EthernetShield                          |
  +------------+------------------+--------+--------+-----------------+--------------------+-----+-----+---------+---------+--------+--------+----------+----------+-----------------------------------------------------------+
  |            |       Wire       |        |        |                 |        |     |     |     |     |         |         |        |        |          |          |                                                           | 
  | 11         | SDA              |  PA08  |  C15   |                 |   NMI  | *16 |     | X00 |     |  *0/00  |   2/00  | TCC0/0 | TCC1/2 | I2S/SD1  |          | -> I2C SDA (SSD1308, EEPROM) / NINA PIO27 (Bootmode-Sel.) |
  | 12         | SCL              |  PA09  |  B16   |                 |   09   | *17 |     | X01 |     |  *0/01  |   2/01  | TCC0/1 | TCC1/3 | I2S/MCK0 |          | -> I2C SCL (SSD1308, EEPROM)                              |
  +------------+------------------+--------+--------+-----------------+--------+-----+-----+-----+-----+---------+---------+--------+--------+----------+----------+-----------------------------------------------------------+
  |            |      Serial1     |        |        |                 |        |     |     |     |     |         |         |        |        |          |          |                                                           |
  | 13         | RX               |  PB23  |  C11   |                 |   07   |     |     |     |     |         |  *5/03  |        |        |          | GCLK_IO1 | <- FPGA RxD <- Behringer X32 Main-Control                 |
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

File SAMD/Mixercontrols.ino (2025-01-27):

void mixerSetVolume(uint8_t channel, float volume) {
  playerinfo.volumeCh[channel] = volume; // we are receiving this value from NINA with a bit delay again

  // send new value to NINA
  SerialNina.println("mixer:volume:ch" + String(channel + 1) + "@" + String(volume, 2));

  #if USE_XREMOTE == 1
    xremoteSetFader(channel+1, (volume + 48.0f)/54.0f);
  #endif
}

void mixerSetBalance(uint8_t channel, uint8_t balance) {
  playerinfo.balanceCh[channel] = balance; // we are receiving this value from NINA with a bit delay again

  // send value to NINA
  SerialNina.println("mixer:balance:ch" + String(channel + 1) + "@" + String(balance));

  #if USE_XREMOTE == 1
    xremoteSetPan(channel+1, balance / 100.0f);
  #endif
}

void mixerSetMainVolume(float volume) {
  playerinfo.volumeMain = volume; // we are receiving this value from NINA with a bit delay again

  // send new value to NINA
  SerialNina.println("mixer:volume:main@" + String(volume, 2));

  #if USE_XREMOTE == 1
    xremoteSetMainFader((volume + 48.0f)/54.0f);
  #endif
}

void mixerSetMainBalance(uint8_t balance) {
  playerinfo.balanceMain = balance; // we are receiving this value from NINA with a bit delay again

  // send value to NINA
  SerialNina.println("mixer:balance:main@" + String(balance));

  #if USE_XREMOTE == 1
    xremoteSetMainPan(balance / 100.0f);
  #endif
}

void mixerSetMute(uint8_t channel, bool mute) {
  if (mute) {
    MackieMCU.channel[channel].mute = 127;
  }else{
    MackieMCU.channel[channel].mute = 0;
  }

  // send value to NINA
  SerialNina.println("mixer:mute:ch" + String(channel+1) + "@" + String(mute));

  // update X32Edit
  #if USE_XREMOTE == 1
    xremoteSetMute(channel+1, MackieMCU.channel[channel].mute);
  #endif
}

void mixerSetSolo(uint8_t channel, bool solo) {
  if (solo) {
    MackieMCU.channel[channel].solo = 127;
  }else{
    MackieMCU.channel[channel].solo = 0;
  }

  // send value to NINA
  SerialNina.println("mixer:solo:ch" + String(channel+1) + "@" + String(solo));

  // update X32Edit
  #if USE_XREMOTE == 1
    xremoteSetSolo(channel+1, MackieMCU.channel[channel].solo);
  #endif
}

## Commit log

2024-11-27 Updated Readme. Added some important input-pins to FPGA. Changed pins of FPGA to match current setup.
2024-11-29 Added Volume-setting for SD-Card and BT. Removed Samplerate-Setting. Added SAMD: before OK. Implemented Ring-Buffer for FPGA-communication. LEDs are fading now. Implemented update-information between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
2024-12-02 Updated webserver for 32 channels. Removed unused webserver-functions.
    [fbape.cfg]
2024-12-05 Audio is now working with a bit-shift-problem somewhere. Working Ethernet-Jack on SAMD21. Working TCP-cmd-server and webserver.
    [Ethernet.ino, SAMD.ino, X32Comm.ino]
2024-12-08 DMX512 is working. Audiomixing is working. SD Card and MP3 is working. Minor fixes in code.
    [Communication.ino, Mixerengine.ino, NINA.ino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]
2024-12-09 Renamed config-file
    [xfbape.cfg]
2024-12-09 Added PCB, GerberFiles and Documentation
    [Connector.SchDoc, FPGA.SchDoc, Top.SchDoc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]
2024-12-10 Fixed several playback-control-commands between X32 and Vidor4000
    [Communication.ino, HelperFunctions.ino, X32Comm.ino]
2024-12-12 Fixed urls in file-headers
    [NINA.ino, SAMD.ino]
2024-12-18 Fixed SERCOM-settings for additional USART-connections
    [MackieMCU.ino, SAMD.ino]
2024-12-22 Optimized behavior of XTouch-motor-faders
2024-12-23 Fixed bug with bitshifted TDM-audio. Improved quality of EQs. New bypass-option for audio-effects when not used. Improved overall audio-quality.
    [Connector.SchDoc, FPGA.SchDoc, Top.SchDoc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]
2025-01-01 Implemented functions for Solo and Mute. Fixed masterfader for MackieMCU. Increased serial baudrate between NINA and SAMD21 to 3Mbps. Added channelnames.
    [Communication.ino, MackieMCU.ino, Mixerengine.ino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]
2025-01-19 Removed old GUIs and updated main-GUI to support all 32 channels and channelnames.
    [CONFIG.TXT, FBAPE.cfg, FBAPE311.cfg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]
2025-01-21 Fixed uart-transmission from FPGA to NINA. Renamed Serial-objects in NINA and SAMD. Fixed and tested uart-baudrate between SAMD and NINA.
    [Communication.ino, Ethernet.ino, HelperFunctions.ino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]
2025-01-24 Fixed timing-issue in FPGA. Fixed several communication-problems. Fixed fader-position at start. Display-color can be set for X-Touch. Optimized VU-meters. Fixed Mute/Solo. Fixed IP-addresses when st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
    [Communication.ino, HelperFunctions.ino, MackieMCU.ino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]
2025-01-24 Optimized behaviour on missing X-Touch. Optimized value-display. Added documentation of commands. Some code-cleanup.
    [Communication.ino, HelperFunctions.ino, MackieMCU.ino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]
2025-01-25 Moved playback-controls to MainCtrl. Fixed and tested multi-XTouch-support.
    [Communication.ino, HelperFunctions.ino, MackieMCU.ino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]
2025-01-25 Muted and soloed channels keep its state while changing volume now. Fixed baudrate-problem on entering bootloader-mode. Changed TDM-receiver to clock-registered to fix timing-issues.
    [Communication.ino]
2025-01-27 Fixed solo-function. Updated readme.
    [Communication.ino, NINA.ino]
